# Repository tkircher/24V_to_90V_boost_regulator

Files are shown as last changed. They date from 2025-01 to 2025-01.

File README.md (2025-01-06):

# 24V_to_90V_boost_regulator
This is a boost regulator to generate 90V to power my coffee grinder DC motor from 24V DC
boost_regulator

This PCB is from a first revision. I used it to successfully power my 90V DC treadmill motor under moderate load.
boost_regulator

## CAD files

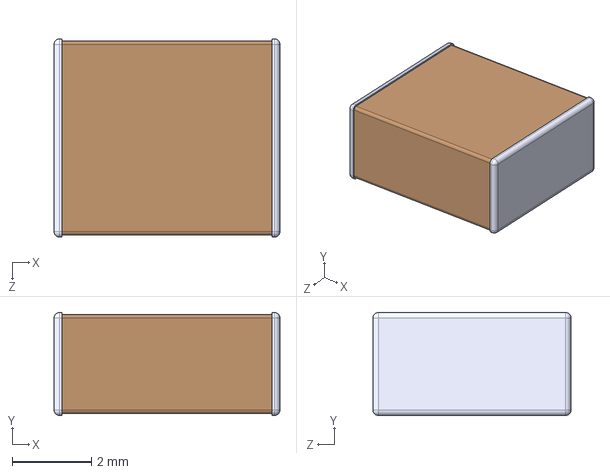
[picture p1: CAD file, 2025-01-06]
3D_models/C5750X7S2A106K230KE.step
5.70 x 2.60 x 5.00 mm

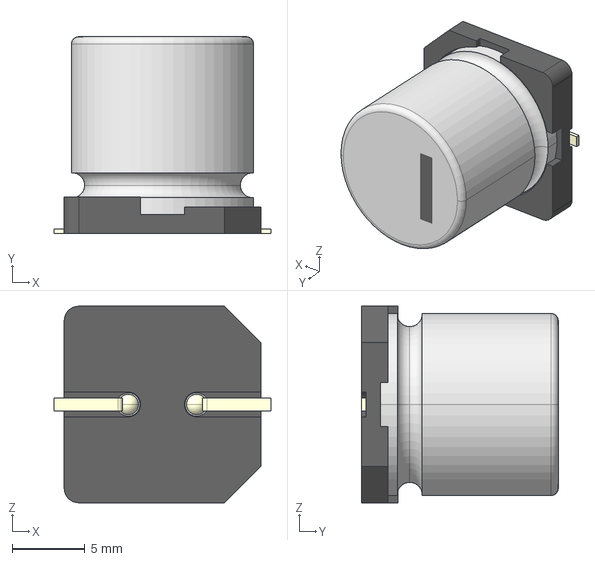
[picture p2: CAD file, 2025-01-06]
3D_models/AFK686M2AH32T-F.stp
14.9 x 13.5 x 13.5 mm

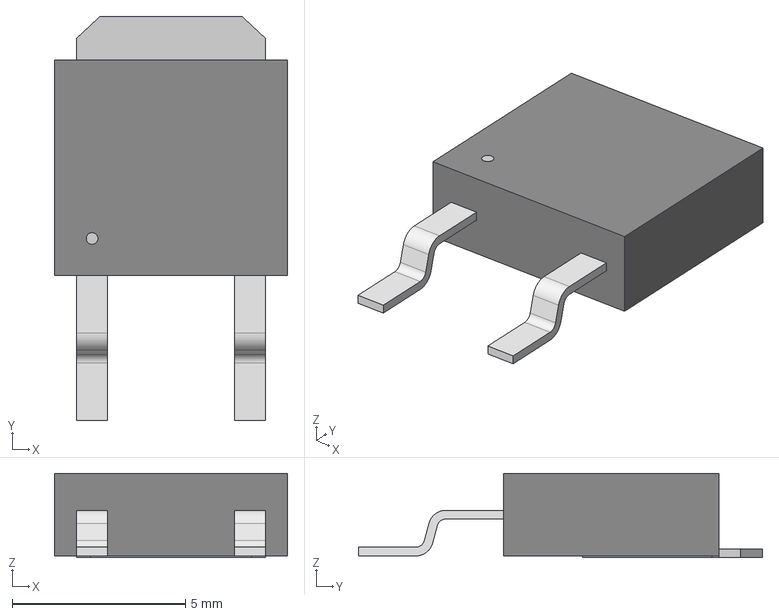
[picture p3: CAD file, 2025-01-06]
3D_models/DPAK_10FN-M3_VIS.step
6.73 x 11.7 x 2.44 mm

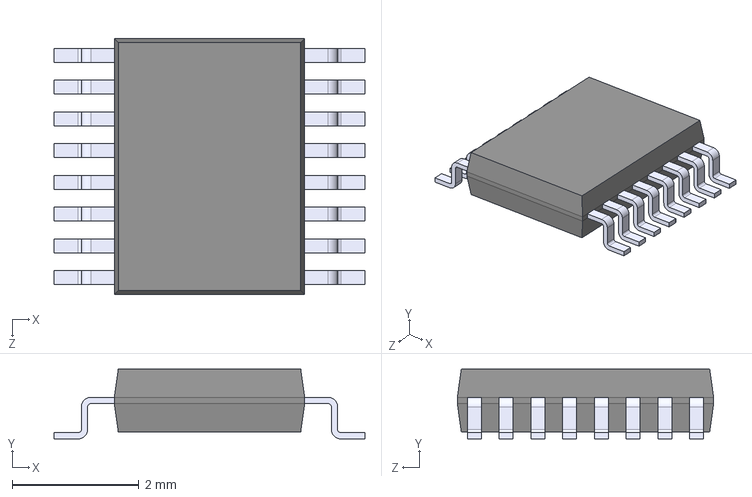
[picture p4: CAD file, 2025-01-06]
3D_models/LTC7000IMSE_TRPBF.step
4.90 x 1.10 x 4.04 mm

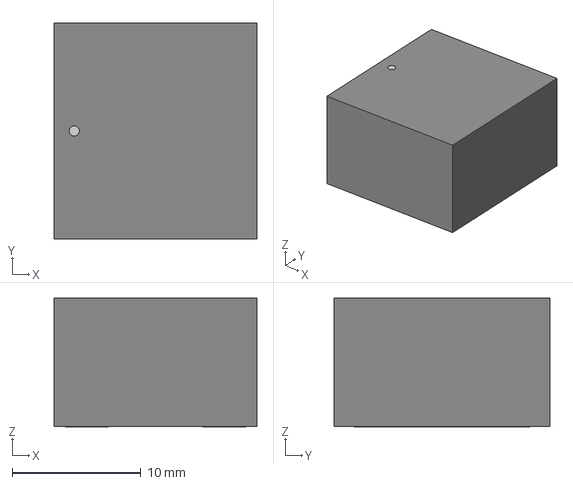
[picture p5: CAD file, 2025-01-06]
3D_models/IND_SRP1510CA_BRN.step
15.8 x 16.8 x 10.0 mm

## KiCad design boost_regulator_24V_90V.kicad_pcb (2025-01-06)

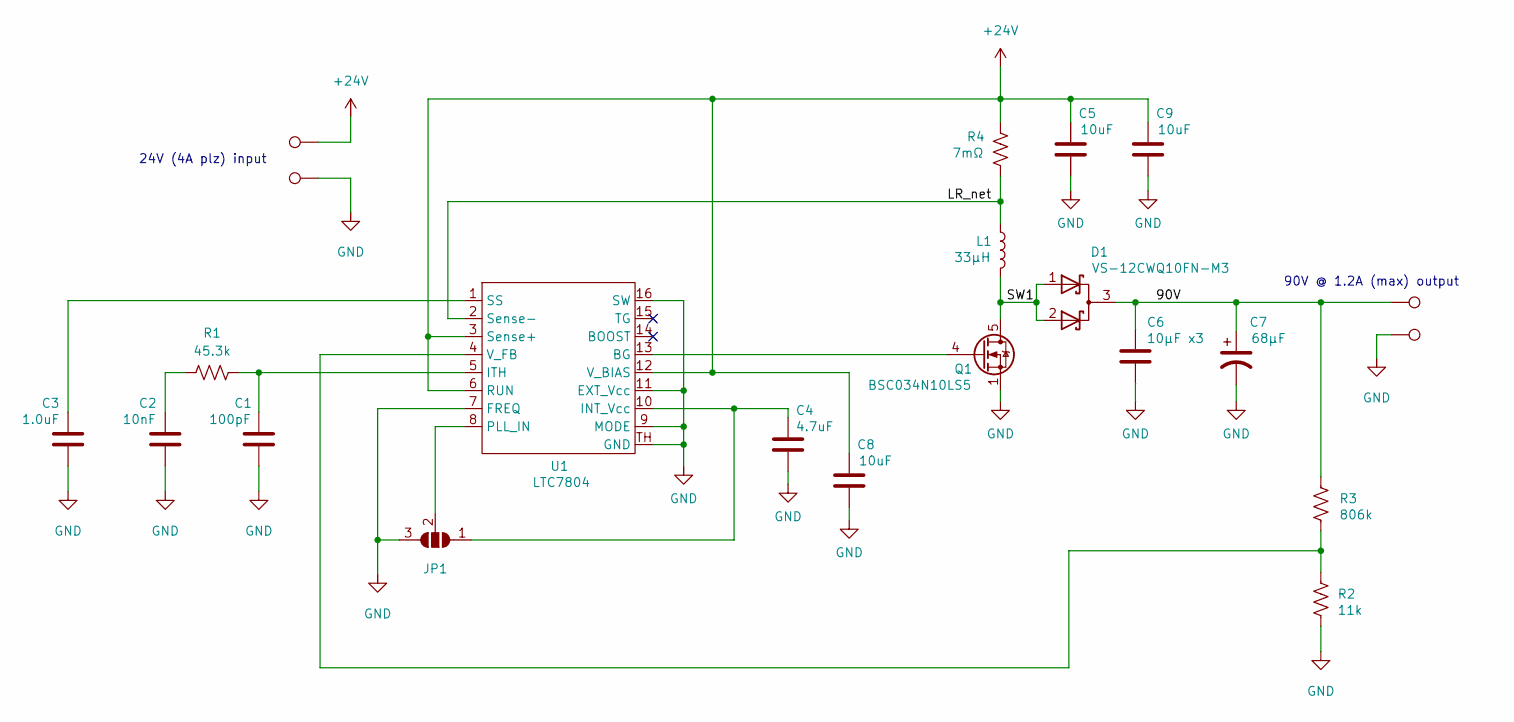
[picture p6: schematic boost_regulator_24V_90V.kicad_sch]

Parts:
C1: 100pF; C_0805_2012Metric
C2: 10nF; C_0805_2012Metric
C3: 1.0uF; C_0805_2012Metric
C4: 4.7uF; R_0805_2012Metric
C5, C8, C9: 10uF; R_1210_3225Metric
C6: 10µF x3; C_2220_5650Metric
C7: 68µF; AFK_H
Conn1: 90V; TestPoint_THTPad_4.0x4.0mm_Drill2.0mm
Conn2: 24V; TestPoint_THTPad_4.0x4.0mm_Drill2.0mm
Conn3, Conn4: GND; TestPoint_THTPad_4.0x4.0mm_Drill2.0mm
D1: VS-12CWQ10FN-M3; D-PAK
JP1: Spread spectrum select; SolderJumper-3_P1.3mm_Open_Pad1.0x1.5mm
L1: 33µH; SRP1510CA
Q1: BSC034N10LS5; TDSON-8-1
R1: 45.3k; R_0805_2012Metric
R2: 11k; R_0805_2012Metric
R3: 806k; R_0805_2012Metric
R4: 7mΩ; WSHM2818
U1: LTC7804; LTC7804_MSOP

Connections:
+24V: C5.1, C8.1, C9.1, Conn2.1, R4.2, U1.3 (Sense+), U1.6 (RUN), U1.12 (V_BIAS)
/90V: C6.1, C7.1, Conn1.1, D1.3 (A), R3.1
/LR_net: L1.1, R4.1, U1.2 (Sense-)
/SW1: D1.1 (K), D1.2 (K), L1.2, Q1.5 (D)
GND: C1.2, C2.2, C3.2, C4.2, C5.2, C6.2, C7.2, C8.2, C9.2, Conn3.1, Conn4.1, JP1.3 (B), Q1.1 (S), Q1.2 (S), Q1.3 (S), R2.2, U1.7 (FREQ), U1.9 (MODE), U1.11 (EXT_Vcc), U1.16 (SW), U1.TH (GND)
unnamed: C2.1, R1.2
unnamed: C4.1, JP1.1 (A), U1.10 (INT_Vcc)
unnamed: JP1.2 (C), U1.8 (PLL_IN)
unnamed: Q1.4 (G), U1.13 (BG)
unnamed: C1.1, R1.1, U1.5 (ITH)
unnamed: C3.1, U1.1 (SS)
unnamed: R2.1, R3.2, U1.4 (V_FB)

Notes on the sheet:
90V @ 1.2A (max) output
24V (4A plz) input

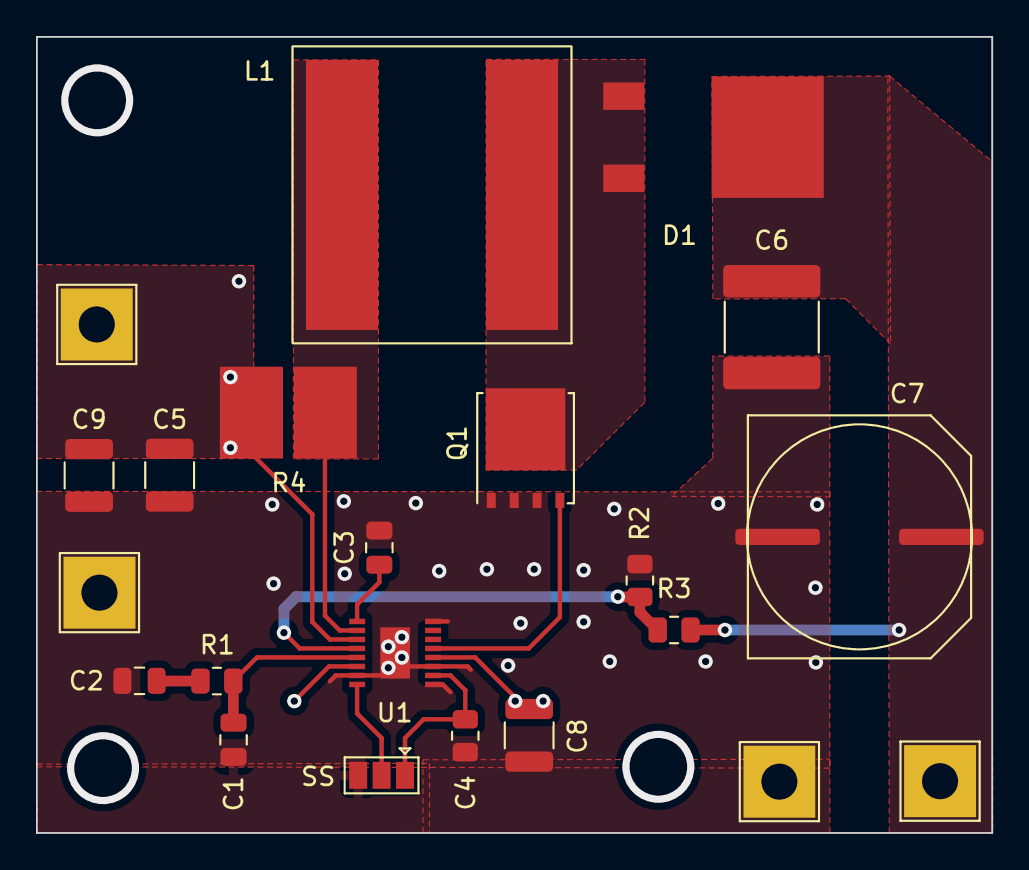
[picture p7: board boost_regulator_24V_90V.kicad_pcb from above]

Board: 2 copper layers, 53.1 x 44.2 mm, 22 parts (0 on the bottom side), 12 nets.
